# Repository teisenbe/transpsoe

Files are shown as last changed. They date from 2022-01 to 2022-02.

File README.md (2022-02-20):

# Transpsoe

This is a Eurorack 1u 22hp module that performs pitch transposition on V/oct signals. Outputs are accurate to within 1.5mV, often better. The panel is designed for Intellijel 1u, but is (untested) compatible with Pulp Logic 1u. Build instructions can be found [here](build_instructions.md). **Note: revs 1 and 2 have not been built yet. Rev 1 but is only minor changes from rev 0, but 2 is more substantial. See the [changelog](CHANGELOG.md) for details.**

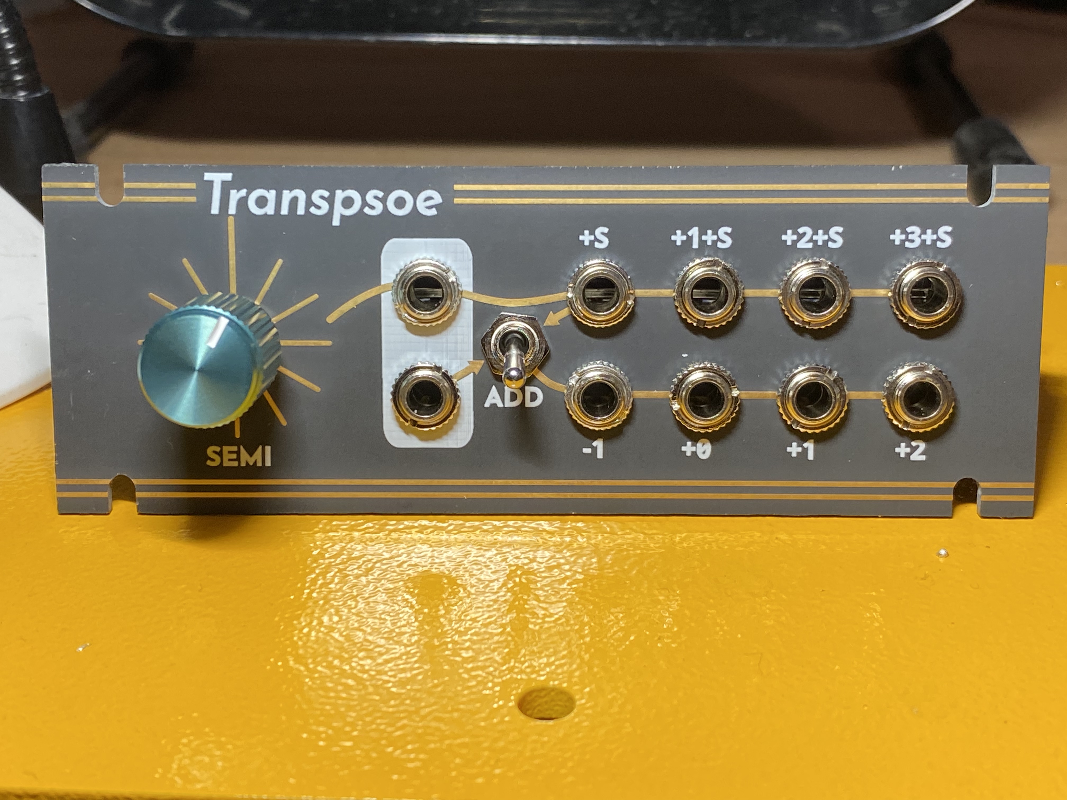
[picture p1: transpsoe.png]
Photo of assembled Transpsoe


## Project Status

- [x] Complete initial CAD work
- [x] SPICE simulations
- [x] Order test board to verify footprints, board alignment, and power connector clearance
- [x] Order and assemble rev 0 PCBs and components
- [ ] Order and assemble rev 2 PCBs and components

## Known issues
- Something on channel 1 produces around -0.5 to -1mV of error in a way that is visible on the +S output (and all channel 2 outputs when summing is enabled). It does not seem to show up on the other outputs, but this might just mean its calibrated out of the voltage refs.

## Controls

Transpsoe has two inputs, 8 outputs, a toggle switch, and a rotary knob. The two rows of jacks corresponds roughly to two channels of operation.

### Inputs

The inputs are identified by white outlines. The jacks are both normed to 0V. Each input is fed to the jacks to their right. The channel summing mechanism can also feed the top input downward.

### Channel summing

The toggle switch can be used to bridge the two channels. If the toggle switch is in the down position, pointing toward the "ADD" label, then the bottom outputs behaves as if the bottom input is increased by the top input and the semitone transposition.

### Semitone transpostion

The rotary knob selects semitone transposition in 12-TET. 0 semitones corresponds to the vertical position, with the extra long radial line.  The number of semitones increases by 1 as you move clockwise. Semitone transposition applies only to the first channel unless channel summing is enabled.

### Outputs

Each output is labeled with an integer representing a number of octaves to shift up the channel's input by. The top channel is also shifted up by the number of semitones selected on the knob.

## Technical details

### Power consumption

- 12V: ~13 mA
- -12V: ~13 mA

### Input/Output voltage limits

All inputs should function fine in the +/- 11V range. All outputs should function fine as long as their expected value is in the +/- 11V range.

### Calibration

1. Apply power to the module.
2. Unplug any patch cables, set the semitone knob to 0, and the summing switch to the off position.
3. Measure the first output on the top. It should be 0V, +/- 1.5mV. This is not adjustable. A substantially different value is indicative of a problem with the circuit.
4. Measure the second output on the top. It should be 1V. Adjust trimpot RV1 to get it as close as possible to 1V.
5. Measure the third and fourth outputs on the top and the first on the bottom. They should be 2V, 3V, and -1V, respectively. They should be pretty close at this point, but if they're not, you can further tune RV1 to minimize the error across the -1V, 1V, 2V, and 3V values.
6. Set the semitone knob to 1 and the summing switch to the off position.
7. Measure the first output on the top. It should be 83.33mV (1/12 mV). Adjust trimpot RV2 to tune as close to 83.33mV as you can, since any error here is going to be multiplied by up to 11.

### Voltage reference

The circuit generates a 4.096V +/- 0.1% reference using a shunt diode. A resistor divider with a trimpot is used to get a 4V reference. -1V, 1V, 2V, and 3V references are generated from the 4V reference.

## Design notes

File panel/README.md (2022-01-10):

The kicad files are generated from the SVG using Inkscape 1.1 and [svg2shenzhen](https://github.com/badgeek/svg2shenzhen).

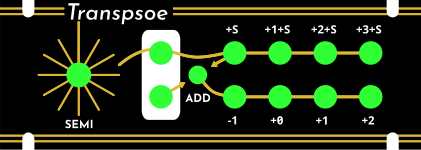
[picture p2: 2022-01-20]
panel/panel.png

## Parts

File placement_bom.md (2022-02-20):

# BOM

| Reference | Part |
| --- | ---- |
|C1|100nF|
|C2|100nF|
|C3|100nF|
|C4|100nF|
|C5|100nF|
|C6|100nF|
|C7|100nF|
|C8|100nF|
|C9|100nF|
|C10|100nF|
|C11|DNI|
|C12|DNI|
|C13|10uF|
|C14|10uF|
|D1|SS14|
|D2|SS14|
|D3|1N4148|
|J1|Audio jack|
|J2|Audio jack|
|J3|Audio jack|
|J4|Audio jack|
|J5|Audio jack|
|J6|Audio jack|
|J7|2x5 pin header|
|J8|Audio jack|
|J9|Audio jack|
|J10|Audio jack|
|J11|Audio jack|
|J12|Samtec SSM-108-L-SV-LC|
|J13|Samtec SSM-108-L-SV-LC|
|J14|Samtec TSM-108-01-F-SV-LC|
|J15|Samtec TSM-108-01-F-SV-LC|
|R1|1M|
|R2|1M|
|R4|100k|
|R5|100k|
|R6|100k|
|R7|100k|
|R9|100k|
|R10|100k|
|R11|100k|
|R12|100k|
|R13|100k|
|R14|100k|
|R16|100k|
|R20|100k|
|R21|100k|
|R22|100k|
|R23|100k|
|R24|330|
|R25|330|
|R26|330|
|R27|330|
|R28|100k|
|R29|100k|
|R30|100k|
|R31|100k|
|R32|100k|
|R33|100k|
|R34|100k|
|R35|100k|
|R40|100k|
|R41|100k|
|R42|100k|
|R43|100k|
|R44|330|
|R45|330|
|R46|330|
|R47|330|
|R48|22k|
|R49|100k|
|R50|39k|
|R330|100k|
|R52|3k|
|R53|1k|
|R54|100k|
|R55|1k|
|R56|1k|
|R57|1k|
|R58|1k|
|R67|110k|
|R68|9.1k|
|R69|10k|
|R70|820|
|R71|10k|
|R72|10k|
|R73|10k|
|R74|10k|
|R75|10k|
|R76|10k|
|R77|10k|
|R78|10k|
|R79|10k|
|R80|10k|
|R81|10k|
|R82|10k|
|RV1|2k|
|RV2|2k|
|SW1|Rotary switch|
|SW2|Toggle switch|
|U1|OPA4991|
|U2|OPA4991|
|U3|OPA4991|
|U4|LM4040|
|U5|OPA4991|
|U6|OPA4991|

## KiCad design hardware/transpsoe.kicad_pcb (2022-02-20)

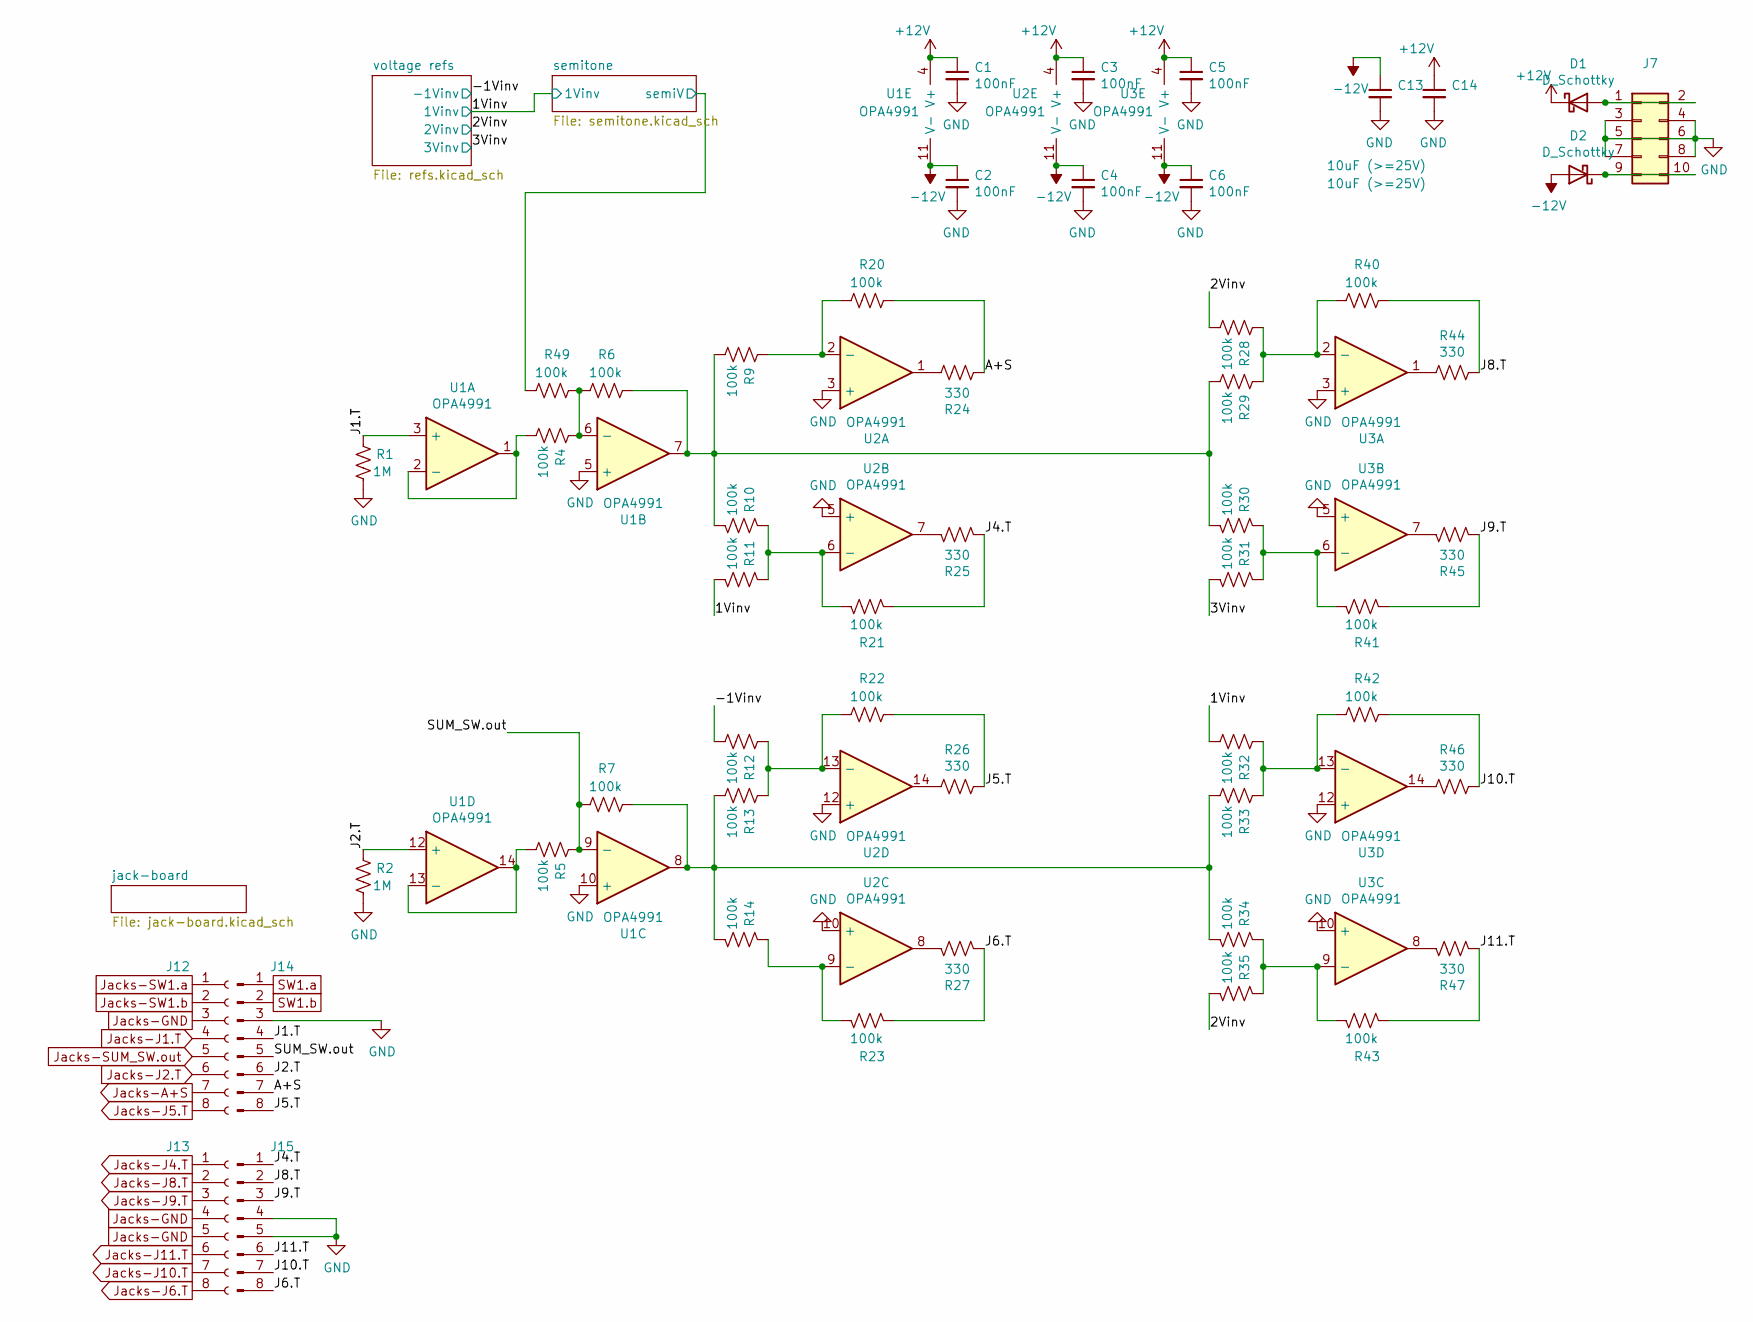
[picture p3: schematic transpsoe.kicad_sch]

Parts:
C1, C2, C3, C4, C5, C6: 100nF; C_0603_1608Metric_Pad1.08x0.95mm_HandSolder
C13, C14: 10uF (>=25V); C_0603_1608Metric_Pad1.08x0.95mm_HandSolder
D1, D2: D_Schottky; D_SMA_Handsoldering
J7: Conn_02x05_Odd_Even; PinHeader_2x05_P2.54mm_Vertical
J12, J13: Conn_01x08_Female; SAMTEC_SSM-108-L-SV-LC
J14, J15: Conn_01x08_Male; SAMTEC_TSM-108-01-F-SV-LC
R1, R2: 1M; R_0603_1608Metric_Pad0.98x0.95mm_HandSolder; Tolerance 5%
R4, R5, R6, R7, R9, R10, R11, R12, R13, R14, R20, R21, R22, R23, R28, R29, R30, R31, R32, R33, R34, R35, R40, R41, R42, R43, R49: 100k; R_0603_1608Metric_Pad0.98x0.95mm_HandSolder; Tolerance 0.1%
R24, R25, R26, R27, R44, R45, R46, R47: 330; R_0603_1608Metric_Pad0.98x0.95mm_HandSolder; Tolerance 5%
U1, U2, U3: OPA4991; SOIC-14_3.9x8.7mm_P1.27mm

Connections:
+12V: C1.1, C3.1, C5.1, C14.1, D1.1 (K), U1.4 (V+), U2.4 (V+), U3.4 (V+); also elsewhere on the board
-12V: C2.1, C4.1, C6.1, C13.1, D2.2 (A), U1.11 (V-), U2.11 (V-), U3.11 (V-); also elsewhere on the board
/1Vinv: R11.2, R32.2; also elsewhere on the board
/2Vinv: R28.2, R35.2; also elsewhere on the board
/3Vinv: R31.2; also elsewhere on the board
/-1Vinv: R12.2; also elsewhere on the board
/A+S: J14.7, R20.1, R24.1
/J1.T: J14.4, R1.1, U1.3 (+)
/J2.T: J14.6, R2.1, U1.12 (+)
/J4.T: J15.1, R21.1, R25.2
/J5.T: J14.8, R22.1, R26.2
/J6.T: J15.8, R23.1, R27.2
/J8.T: J15.2, R40.1, R44.2
/J9.T: J15.3, R41.1, R45.2
/J10.T: J15.7, R42.1, R46.2
/J11.T: J15.6, R43.1, R47.2
/SUM_SW.out: J14.5, R5.1, R7.2, U1.9 (-)
GND: C1.2, C2.2, C3.2, C4.2, C5.2, C6.2, C13.2, C14.2, J7.3, J7.4, J7.5, J7.6, J7.7, J7.8, J14.3, J15.4, J15.5, R1.2, R2.2, U1.5 (+), U1.10 (+), U2.3 (+), U2.5 (+), U2.10 (+), U2.12 (+), U3.3 (+), U3.5 (+), U3.10 (+), U3.12 (+); also elsewhere on the board
Jacks-A+S: J12.7; also elsewhere on the board
Jacks-GND: J12.3, J13.4, J13.5; also elsewhere on the board
Jacks-J1.T: J12.4; also elsewhere on the board
Jacks-J2.T: J12.6; also elsewhere on the board
Jacks-J4.T: J13.1; also elsewhere on the board
Jacks-J5.T: J12.8; also elsewhere on the board
Jacks-J6.T: J13.8; also elsewhere on the board
Jacks-J8.T: J13.2; also elsewhere on the board
Jacks-J9.T: J13.3; also elsewhere on the board
Jacks-J10.T: J13.7; also elsewhere on the board
Jacks-J11.T: J13.6; also elsewhere on the board
Jacks-SUM_SW.out: J12.5; also elsewhere on the board
Jacks-SW1.a: J12.1; also elsewhere on the board
Jacks-SW1.b: J12.2; also elsewhere on the board
unnamed: D1.2 (A), J7.1, J7.2
unnamed: D2.1 (K), J7.9, J7.10
unnamed: R4.1, R6.2, R49.1, U1.6 (-)
unnamed: R4.2, U1.1, U1.2 (-)
unnamed: R5.2, U1.13 (-), U1.14
unnamed: R10.1, R11.1, R21.2, U2.6 (-)
unnamed: R6.1, R9.2, R10.2, R29.2, R30.2, U1.7
unnamed: R12.1, R13.1, R22.2, U2.13 (-)
unnamed: R7.1, R13.2, R14.2, R33.2, R34.2, U1.8
unnamed: R14.1, R23.2, U2.9 (-)
unnamed: R9.1, R20.2, U2.2 (-)
unnamed: R25.1, U2.7
unnamed: R26.1, U2.14
unnamed: R27.1, U2.8
unnamed: R28.1, R29.1, R40.2, U3.2 (-)
unnamed: R30.1, R31.1, R41.2, U3.6 (-)
unnamed: R32.1, R33.1, R42.2, U3.13 (-)
unnamed: R34.1, R35.1, R43.2, U3.9 (-)
unnamed: R44.1, U3.1
unnamed: R45.1, U3.7
unnamed: R46.1, U3.14
unnamed: R47.1, U3.8
unnamed: R24.2, U2.1
SW1.a: J14.1; also elsewhere on the board
SW1.b: J14.2, R49.2; also elsewhere on the board

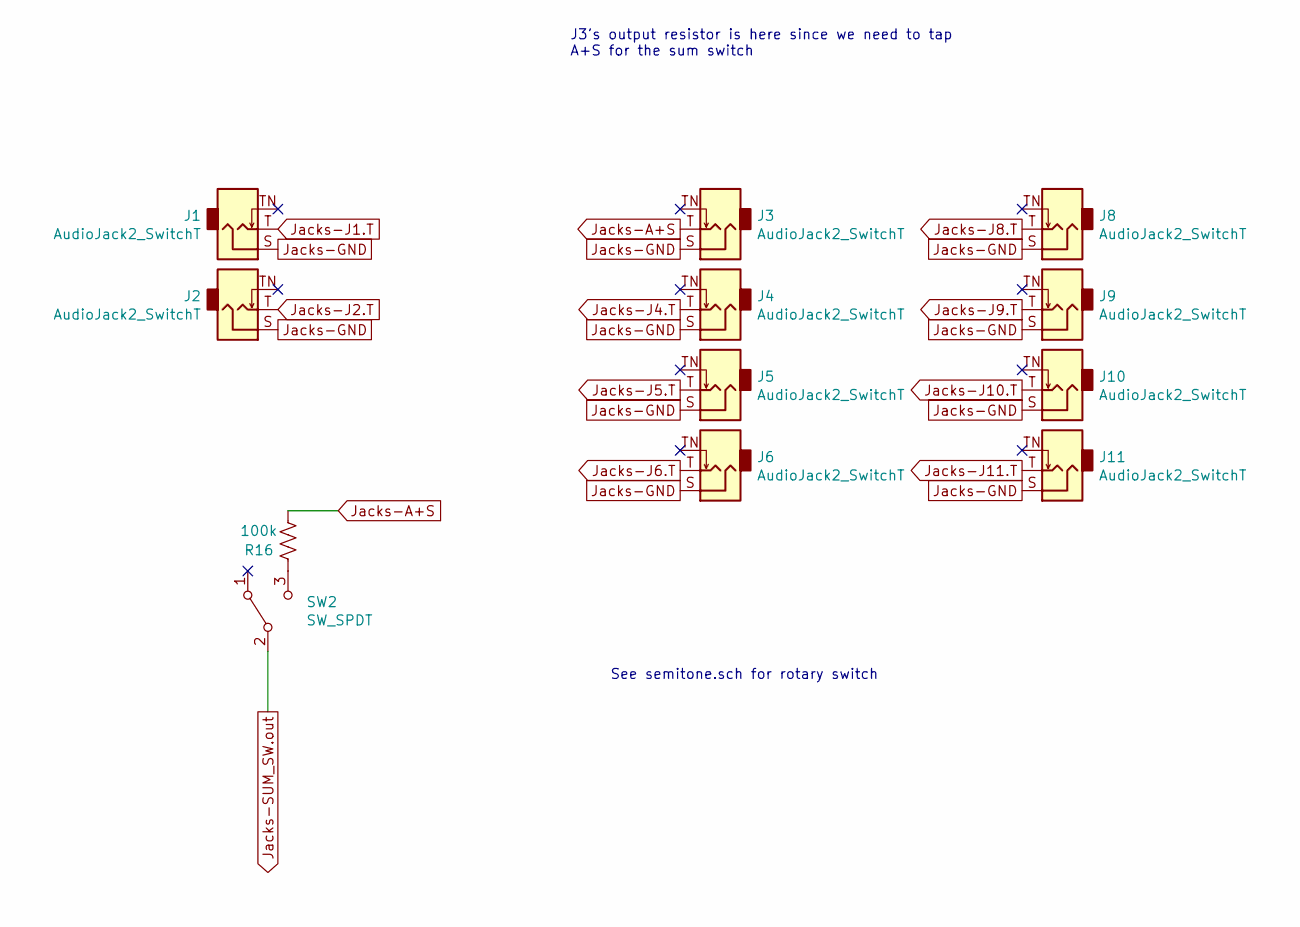
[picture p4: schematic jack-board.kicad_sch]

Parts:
J1, J2, J3, J4, J5, J6, J8, J9, J10, J11: AudioJack2_SwitchT; PJ-301BM
R16: 100k; R_0603_1608Metric_Pad0.98x0.95mm_HandSolder; Tolerance 0.1%
SW2: SW_SPDT; BNT11SEA5QE

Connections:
Jacks-A+S: J3.T, R16.2; also elsewhere on the board
Jacks-GND: J1.S, J2.S, J3.S, J4.S, J5.S, J6.S, J8.S, J9.S, J10.S, J11.S; also elsewhere on the board
Jacks-J1.T: J1.T; also elsewhere on the board
Jacks-J2.T: J2.T; also elsewhere on the board
Jacks-J4.T: J4.T; also elsewhere on the board
Jacks-J5.T: J5.T; also elsewhere on the board
Jacks-J6.T: J6.T; also elsewhere on the board
Jacks-J8.T: J8.T; also elsewhere on the board
Jacks-J9.T: J9.T; also elsewhere on the board
Jacks-J10.T: J10.T; also elsewhere on the board
Jacks-J11.T: J11.T; also elsewhere on the board
Jacks-SUM_SW.out: SW2.2 (B); also elsewhere on the board
unnamed: R16.1, SW2.3 (C)

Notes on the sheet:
See semitone.sch for rotary switch
J3's output resistor is here since we need to tap A+S for the sum switch

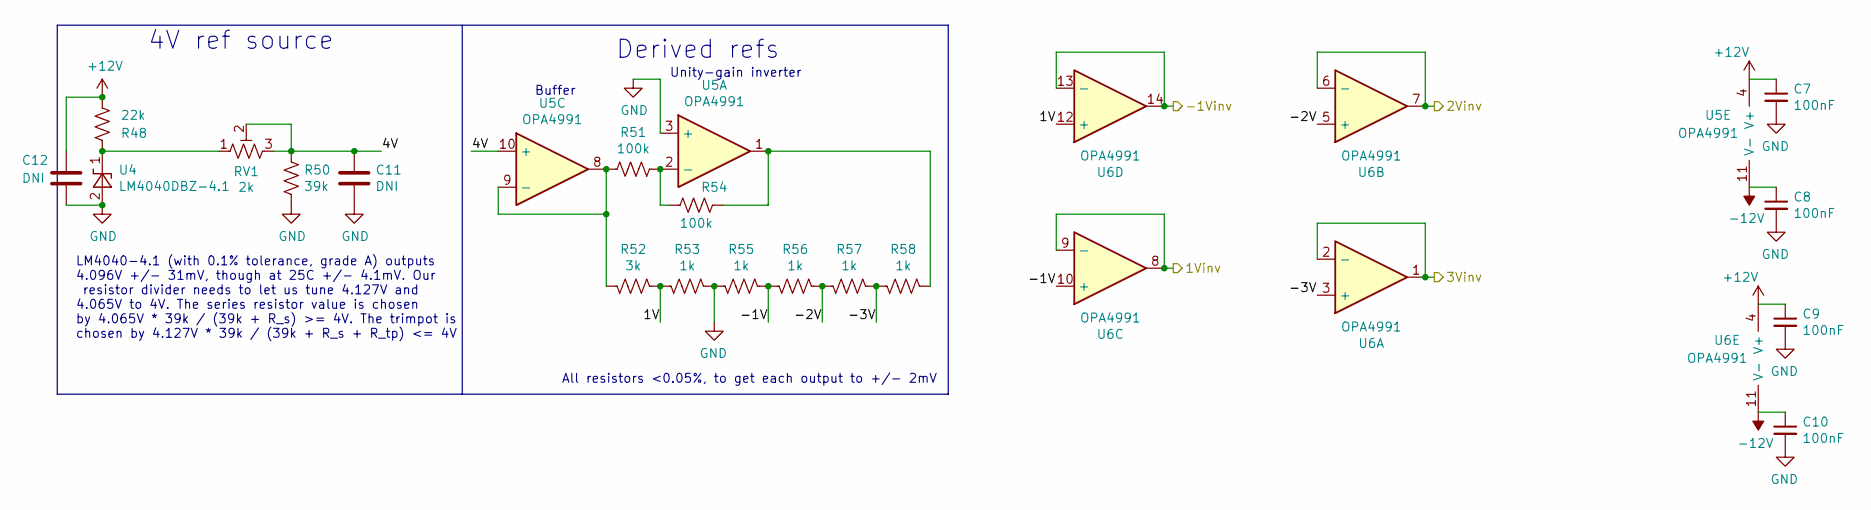
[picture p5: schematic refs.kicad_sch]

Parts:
C7, C8, C9, C10: 100nF; C_0603_1608Metric_Pad1.08x0.95mm_HandSolder
C11, C12: DNI; C_0603_1608Metric_Pad1.08x0.95mm_HandSolder
R48: 22k; R_0603_1608Metric_Pad0.98x0.95mm_HandSolder; Tolerance 1%
R50: 39k; R_0603_1608Metric_Pad0.98x0.95mm_HandSolder; Tolerance 1%, but low temp co
R51, R54: 100k; R_0603_1608Metric_Pad0.98x0.95mm_HandSolder; Tolerance 0.1%
R52: 3k; R_0603_1608Metric_Pad0.98x0.95mm_HandSolder; Tolerance 0.05%, low temp co
R53, R55, R56, R57, R58: 1k; R_0603_1608Metric_Pad0.98x0.95mm_HandSolder; Tolerance 0.05%, low temp co
RV1: 2k; Potentiometer_Bourns_3296W_Vertical; Tolerance 10%
U4: LM4040DBZ-4.1; SOT-23; Tolerance 0.1%
U5, U6: OPA4991; SOIC-14_3.9x8.7mm_P1.27mm

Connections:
+12V: C7.1, C9.1, C12.1, R48.1, U5.4 (V+), U6.4 (V+); also elsewhere on the board
-12V: C8.1, C10.1, U5.11 (V-), U6.11 (V-); also elsewhere on the board
/1Vinv: U6.8, U6.9 (-); also elsewhere on the board
/2Vinv: U6.6 (-), U6.7; also elsewhere on the board
/3Vinv: U6.1, U6.2 (-); also elsewhere on the board
/-1Vinv: U6.13 (-), U6.14; also elsewhere on the board
/voltage refs/1V: R52.2, R53.1, U6.12 (+)
/voltage refs/4V: C11.1, R50.1, RV1.2, RV1.3, U5.10 (+)
/voltage refs/-1V: R55.2, R56.1, U6.10 (+)
/voltage refs/-2V: R56.2, R57.1, U6.5 (+)
/voltage refs/-3V: R57.2, R58.1, U6.3 (+)
GND: C7.2, C8.2, C9.2, C10.2, C11.2, C12.2, R50.2, R53.2, R55.1, U4.2 (A), U5.3 (+); also elsewhere on the board
unnamed: R48.2, RV1.1, U4.1 (K)
unnamed: R51.1, R54.2, U5.2 (-)
unnamed: R51.2, R52.1, U5.8, U5.9 (-)
unnamed: R54.1, R58.2, U5.1

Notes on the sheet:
Derived refs
Unity-gain inverter
All resistors <0.05%, to get each output to +/- 2mV
4V ref source
LM4040-4.1 (with 0.1% tolerance, grade A) outputs 4.096V +/- 31mV, though at 25C +/- 4.1mV. Our resistor divider needs to let us tune 4.127V and 4.065V to 4V. The series resistor value is chosen by 4.065V * 39k / (39k + R_s) >= 4V. The trimpot is chosen by 4.127V * 39k / (39k + R_s + R_tp) <= 4V
Buffer

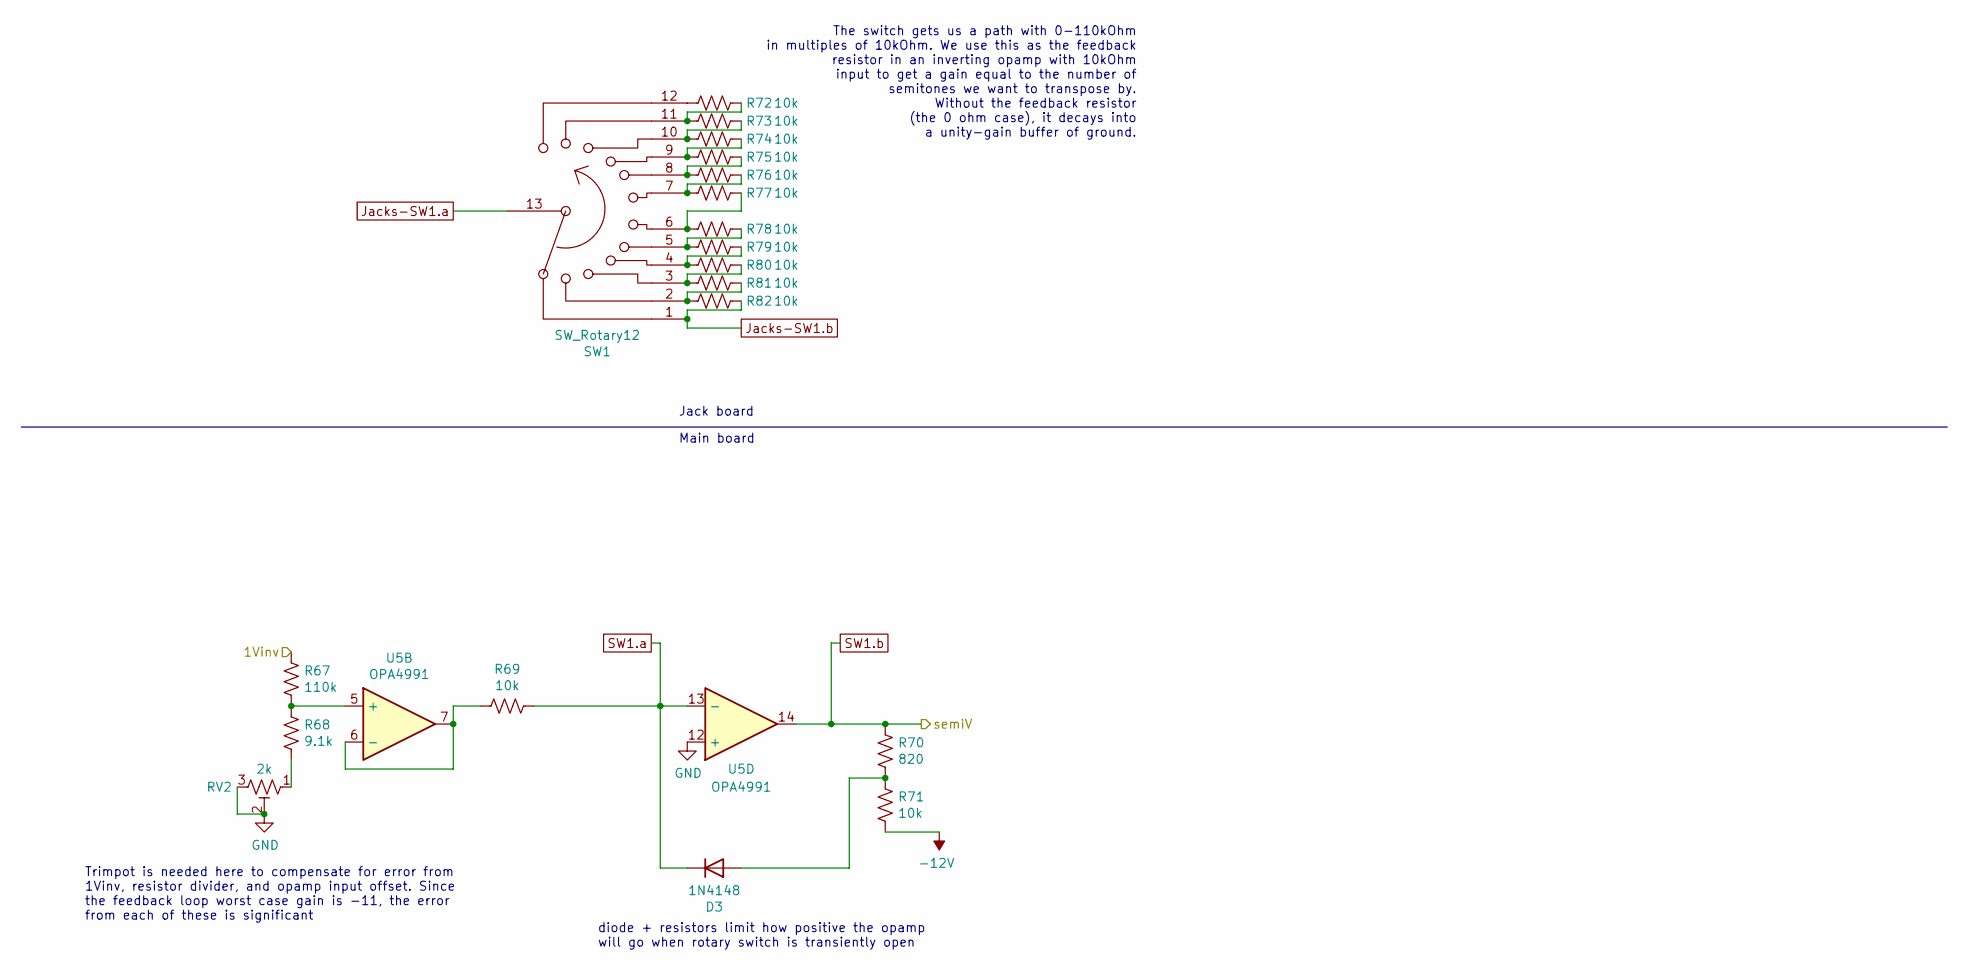
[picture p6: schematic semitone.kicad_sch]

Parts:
D3: 1N4148; D_SOD-123
R67: 110k; R_0603_1608Metric_Pad0.98x0.95mm_HandSolder; Tolerance 1%, low temp co
R68: 9.1k; R_0603_1608Metric_Pad0.98x0.95mm_HandSolder; Tolerance 1%
R69, R72, R73, R74, R75, R76, R77, R78, R79, R80, R81, R82: 10k; R_0603_1608Metric_Pad0.98x0.95mm_HandSolder; Tolerance 0.1%
R70: 820; R_0603_1608Metric_Pad0.98x0.95mm_HandSolder; Tolerance 1%
R71: 10k; R_0603_1608Metric_Pad0.98x0.95mm_HandSolder; Tolerance 1%
RV2: 2k; Potentiometer_Bourns_3296W_Vertical; Tolerance 10%
SW1: SW_Rotary12; MC12xxxCxx
U5: OPA4991; SOIC-14_3.9x8.7mm_P1.27mm

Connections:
-12V: R71.2; also elsewhere on the board
/1Vinv: R67.2; also elsewhere on the board
GND: RV2.2, RV2.3, U5.12 (+); also elsewhere on the board
Jacks-SW1.a: SW1.13; also elsewhere on the board
Jacks-SW1.b: R82.2, SW1.1; also elsewhere on the board
unnamed: D3.2 (A), R70.2, R71.1
unnamed: R67.1, R68.2, U5.5 (+)
unnamed: R68.1, RV2.1
unnamed: R69.2, U5.6 (-), U5.7
unnamed: R72.1, SW1.12
unnamed: R72.2, R73.1, SW1.11
unnamed: R73.2, R74.1, SW1.10
unnamed: R74.2, R75.1, SW1.9
unnamed: R75.2, R76.1, SW1.8
unnamed: R76.2, R77.1, SW1.7
unnamed: R77.2, R78.1, SW1.6
unnamed: R78.2, R79.1, SW1.5
unnamed: R79.2, R80.1, SW1.4
unnamed: R80.2, R81.1, SW1.3
unnamed: R81.2, R82.1, SW1.2
SW1.a: D3.1 (K), R69.1, U5.13 (-); also elsewhere on the board
SW1.b: R70.1, U5.14; also elsewhere on the board

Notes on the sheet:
diode + resistors limit how positive the opamp will go when rotary switch is transiently open
Trimpot is needed here to compensate for error from 1Vinv, resistor divider, and opamp input offset. Since the feedback loop worst case gain is -11, the error from each of these is significant
Jack board
Main board
The switch gets us a path with 0-110kOhm in multiples of 10kOhm. We use this as the feedback resistor in an inverting opamp with 10kOhm input to get a gain equal to the number of semitones we want to transpose by. Without the feedback resistor (the 0 ohm case), it decays into a unity-gain buffer of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

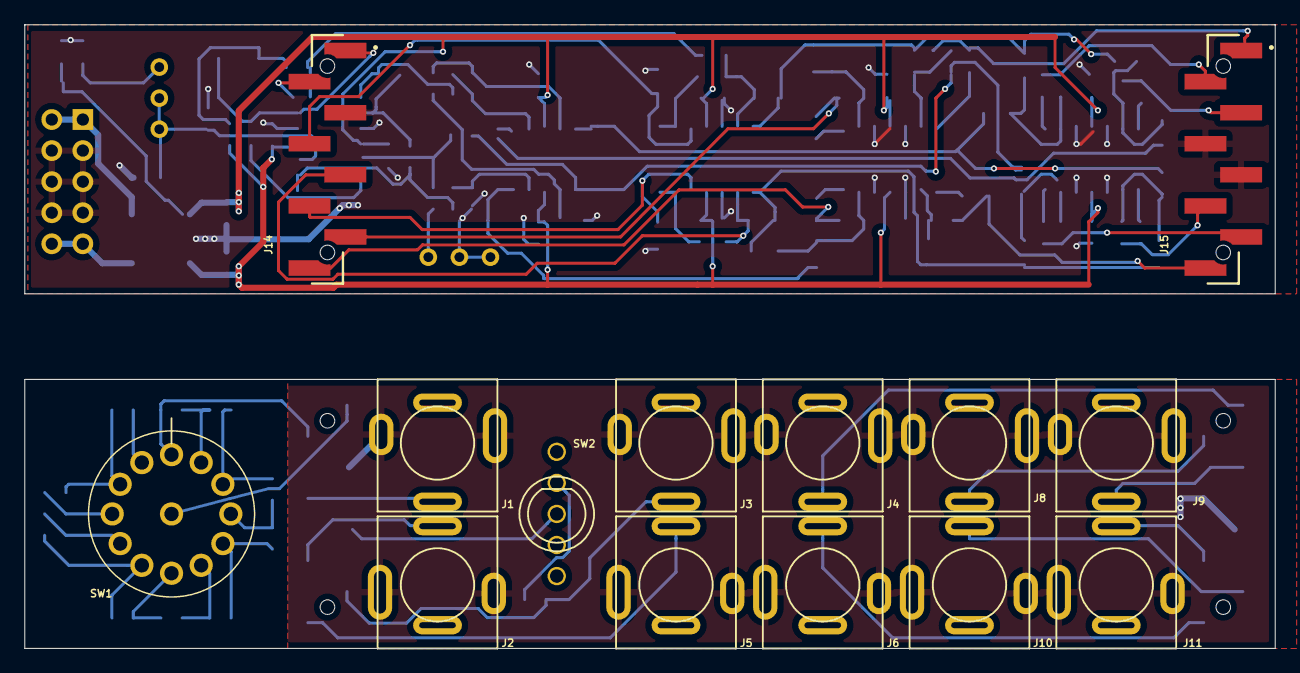
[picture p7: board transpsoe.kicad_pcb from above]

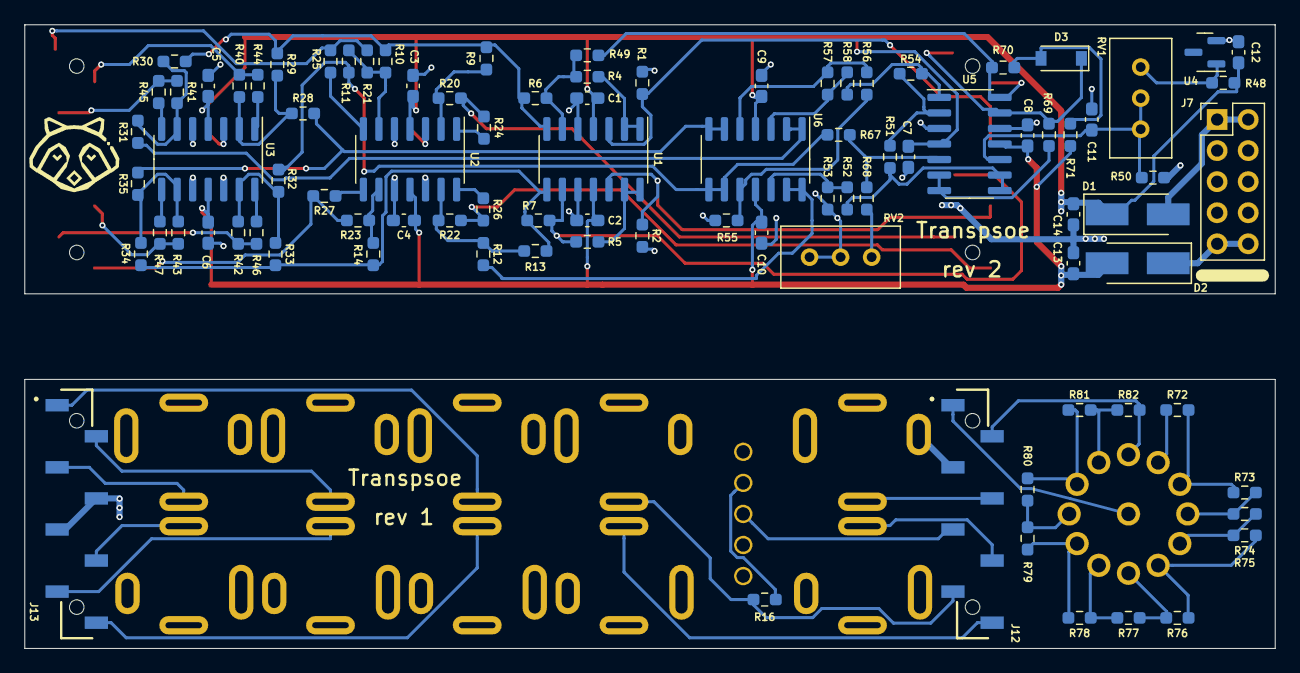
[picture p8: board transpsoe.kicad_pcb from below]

Board: 2 copper layers, 102.2 x 51.0 mm, 107 parts (93 on the bottom side), 82 nets.

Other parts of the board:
svg2mod: G***; raccoon-7.5

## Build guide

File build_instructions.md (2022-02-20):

# Build Instructions

## BOM

| References | Quantity | Part Requirements | Example parts |
| --- | --- | --- | --- |
| C1-C10 | 10 | 100nF 0603, >= 25V | Samsung CL10B104KA8NNNC |
| C11, C12 | 2 | DNI | |
| C13, C14 | 2 | 10uF 0603, >=25V | Murata GRM188R61E106KA73D |
| D1, D2 | 2 | Schottky diode, >24V reverse voltage, SMA footprint | SS14 |
| D3 | 1 | 1N4148, SOD-123 | SMC Diode Solutions 1N4148WTR |
| J1-J6, J8-J11 | 10 | Compatible with Wenzhou QingPu WQP-WQP518MA-BM | WQP-WQP518MA-BM, WQP-PJ398S-BM, WQP-PJ301BM |
| J7 | 1 | Unshrouded 2x5 vertical pin header, 2.54mm pitch, through hole | Amphenol 67997-210HLF, or Tayda A-198 if you don't mind splitting headers yourself |
| J12, J13 | 2 | Samtec SSM-108-L-SV-LC | Samtec SSM-108-L-SV-LC |
| J14, J15 | 2 | Samtec TSM-108-01-F-SV-LC | Samtec TSM-108-01-F-SV-LC |
| R1, R2 | 2 | 1M 0603 (any tolerance) | Walsin WR06X105 JTL |
| R4-R7, R9-R14, R16, R20-R23, R28-R35, R40-R43, R49, R51, R54 | 30 | 100k 0603 0.1% | YAGEO RT0603BRB07100KL |
| R24-R27, R44-R47 | 8 | 330 0603 5% | |
| R48 | 1 | 22k 0603 1% | Walsin WR06X2202FTL |
| R50 | 1 | 39k 0603 1%, low temp co | Panasonic ERA-3VRW3902V |
| R52 | 1 | 3k 0603 0.05% low temp co | Susumu RG1608N-302-W-T1 |
| R53, R55-R58 | 5 | 1k 0603 0.05%, low temp co | Panasonic ERA-3VRW1001V |
| R67 | 1 | 110k 0603 1%, low temp co  | TE Connectivity RN73C1J110KBTD |
| R68 | 1 | 9.1k 0603 1% | YAGEO RT0603DRE079K1L |
| R69, R71-R82 | 13 | 10k 0603 0.1% | KOA Speer RN73R1JTTD1002B10 |
| R70 | 1 | 820R 0603 1%  | Stackpole Electronics RMCF0603FT820R |
| RV1, RV2 | 2 | 2k 10%, compatible with Bourns 3296W footprint, high turn count | Bourns 3296W-1-202RLF |
| SW1 | 1 | C&K Switches M-series rotary switch, 12 position | Any of CK's MC12xxNCxx, MC00xxNCxx, or MG00xxNCxx. I recommended one of the 00s, since they can move between positions 12 and 1 in one click. I like the D-shaft ones due to ease of alignment of indicators |
| SW2 | 1 | SPDT (or even SPST) toggle switch compatible with CIT Relay's BNT11SEA5QE or BNT11SECQE footprints, ideally with similar dimensions to either of those. If using a 3-pin part, use the center 3 holes of the footprint | CIT Relay's BNT11SEA5\*E or BNT11SEC\*E, CK's T101SHC\* or T101SHV3\*, E-Switch's 200-MSP1TB1M2\* or 200-MSP1T1B1VS2\*, Tayda's A-5290 (unverified compatibility)
| U1-U3, U5, U6 | 5 | Low-input offset quad op-amp compatible with TI OPA4991 pinout, supports dual supply with spans of 20V-28V, 14-SOIC | TI OPA4991QDRQ1 |
| U4 | 1 | LM4040 4.096V 0.1% reference, SOT23-3 | Analog Devices LM4040AIM3-4.1+T |

You will likely want to buy a [1/4in to 1/8in shaft adapter](https://www.amplifiedparts.com/products/potentiometer-adapter-sleeve-converts-125-shaft-14) for the rotary switch.

For convenience, [here's the BOM with one line per reference](placement_bom.md)

## Important notes

If you're building a rev 0 board, note that
- the C2 & R5 reference designators are swapped on the board, and
- the R44 & R30 reference deisgnators are swapped on the board

Silkscreen conventions:
- ICs have a long line to pin 1
- Diodes have a U-shape mark on the cathode (negative side)
- Jacks, switches, and trimpots are outlined on the side their body is on

## Assembly

1. **Read the [Important notes section](#important-notes)**.
1. Start with the main board and solder all of the surface mount components on the raccoon side. You can do this however you want; I like to move from one end of the board to the other.
1. Flip the board over and solder J14 & J15. Do not attempt to remove them from the board once the retaining clips have been inserted, as this will likely rip the retaining clips out of the part. The retaining clips work fairly well for positioning, but solder one pin and double check the connector looks square to the board. Solder the rest of their pins.
1. Flip the board back over and solder J7. Make sure this header is on the side with the raccoon. Solder one pin, double check the connector is square and is on the right side of the board. Solder the rest of its pins.
1. Solder RV1 and RV2. The plastic bodies should be on the side with the raccoon. Solder one pin, check the trimpot is square, then solder the rest of the pins.
1. Set aside the main board and move on to the jack board.
1. Solder all of the resistors on the jack board.
1. Insert (but don't solder) all of the audio jacks with their bodies on the opposite side of the board from the resistors.
1. Put the panel on top of the audio jacks and loosely tighten the jack nuts.
1. Flip over the panel and jack board and solder one pin on each audio jack. Remove the jack nuts and panel and verify jacks look square. Solder the rest of the audio jack pins.
1. Place SW1, making sure pin 1 is aligned with the vertical line at the top. Secure SW1 to the board with tape or some other means, and solder one pin. Double check the switch is square to the board, then solder the rest of the pins.
1. Place SW2. If using a 3-pin device, use the middle 3 holes. Secure the switch to the board, and solder one pin. Double check it's square to the board, then solder the rest of the pins.
1. Place and solder J12 & J13 like you did with J14 & J15.
1. Put the panel back on and secure all jack and switch nuts. You may want to place an additional nut or shim on each switch so the board rests on it instead of being compressed into the air.

## Powering on and calibrating

1. Test the power header for shorts.
1. Connect a power cable to the header with the -12V (red) side next to the thick white silkscreen line.
1. Follow the [calibration guide](README.md#calibration).

If you're having trouble, feel free to file an issue on GitHub and I'll try to help if I have time.

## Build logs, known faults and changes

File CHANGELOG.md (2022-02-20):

# Change log

This document describes the changes between board revisions

## Main board

### Rev 2
- Redesigned output circuits to have better current limiting and improved stiffness

### Rev 1
- Fixed C2 & R5 refdes swap on PCB
- Fixed R44 & R30 refdes swap on PCB
- Fixed R46 label off board
- Fixed D2 label off board
- Fixed C11 label on pad
- Fixed U4 label off board
- Fixed via stitching on -12V rail
- Migrate to KiCad6 footprints for caps and resistors (caps are now slightly longer, resistors are now shorter)

## Jack board

### Rev 1
- Added revision marker

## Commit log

2022-01-11 Rotate rotary knob so pin 1 is facing up
    This brings it into alignment with the panel's 0 indicator
    [transpsoe.kicad_pcb]
2022-01-11 Update rotary switch footprint to make pin 1 point up
2022-01-11 Use different nets for main versus jack board
    This gets rid of the 14 spurious "Unconnected Items" DRCs, and makes
    it more explicit which parts are on which board.
    [jack-board.sch, refs.sch, semitone.sch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]
2022-01-11 Remove unnecessary circuit on "up" position of toggle switch
    An open circuit will work just as well as a resistor to ground, with
    fewer parts.
    [jack-board.sch, transpsoe.kicad_pcb]
2022-01-11 Remove accidental Notes fields on resistors
    [jack-board.sch, transpsoe.sch]
2022-01-11 Correct datasheet for rotary switch
    [semitone.sch]
2022-01-11 Rework semitone circuit
    - Flip the polarity of the voltage limiter, which accidentally wasn't
    inverted when the subcircuit's output polarity was inverted earlier
    in the design work.
    - Add a trimpot to the semitone voltage reference, to compensate for
    various sources of error
    - Add to the spice model to allow testing the error on the semitone
    output
    [jack-board.sch, refs.sch, semitone.sch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]
2022-01-11 Remove extra calibration instruction
2022-01-12 Document part selection suggestions
    [jack-board.sch, refs.sch, semitone.sch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]
2022-01-13 Narrow boards by 0.5mm
    It's not a lot, but it gives us a little extra margin in fit-up
    [transpsoe.kicad_pcb]
2022-01-14 Increase annular ring size on rotary switch
    [transpsoe.kicad_pcb]
2022-01-15 Update suggested trimpot
    [refs.sch, semitone.sch]
2022-01-17 Correct orientation of summing switch
    [transpsoe.kicad_pcb]
2022-01-17 Call out resistors where low temp co is important
    [refs.sch, semitone.sch]
2022-01-19 Change fonts on panel
    Also add a script for fixing up the panel to have
    non-plated thru holes
    [transpsoe.kicad_pcb]
2022-01-19 Extend panel to 22hp to increase power cable clearance
    [transpsoe.kicad_pcb]
2022-01-19 Push 3.5mm jacks 0.05mm closer to the edge
    It's a very small nudge, and puts them more at risk of being slightly
    off the board, but increases the tolerances for clearance between
    adjacent jacks. We have ~0.5mm of clearance on the side of the board,
    and this should only eat into at most 0.1mm of it.
    [transpsoe.kicad_pcb]
2022-01-30 Fix issues with board and bump rev
    Errata fixed:
    - C2 & R5 refdes were swapped on PCB
    - R44 & R30 refdes were swapped on PCB
    - R46 label off board
    - D2 label off board
    - C11 label on pad
    - U4 label off board
    - Fix via stitching on -12V
    - Added rev marker to jack board
    - Migrated to KiCad 6
    - Added CHANGELOG.md
    [jack-board.kicad_sch, jack-board.sch, refs.kicad_sch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]
2022-01-30 Fix 3d models and migrate to KiCad6 R/C footprints
    [jack-board.kicad_sch, refs.kicad_sch, semitone.kicad_sch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]
2022-02-06 Document I/O voltage limits
2022-02-20 Redesign output circuits
    [jack-board.kicad_sch, refs.kicad_sch, semitone.kicad_sch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]
